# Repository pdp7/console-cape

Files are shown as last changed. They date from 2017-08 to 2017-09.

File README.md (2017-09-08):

# console-cape
"psuedo" cape for the BeagleBone to display the serial console from the FTDI header on a TFT LCD.  The purpose is to be able to view U-Boot bootloader messages from the BeagleBone without having to have a laptop and USB-to-serial cable.

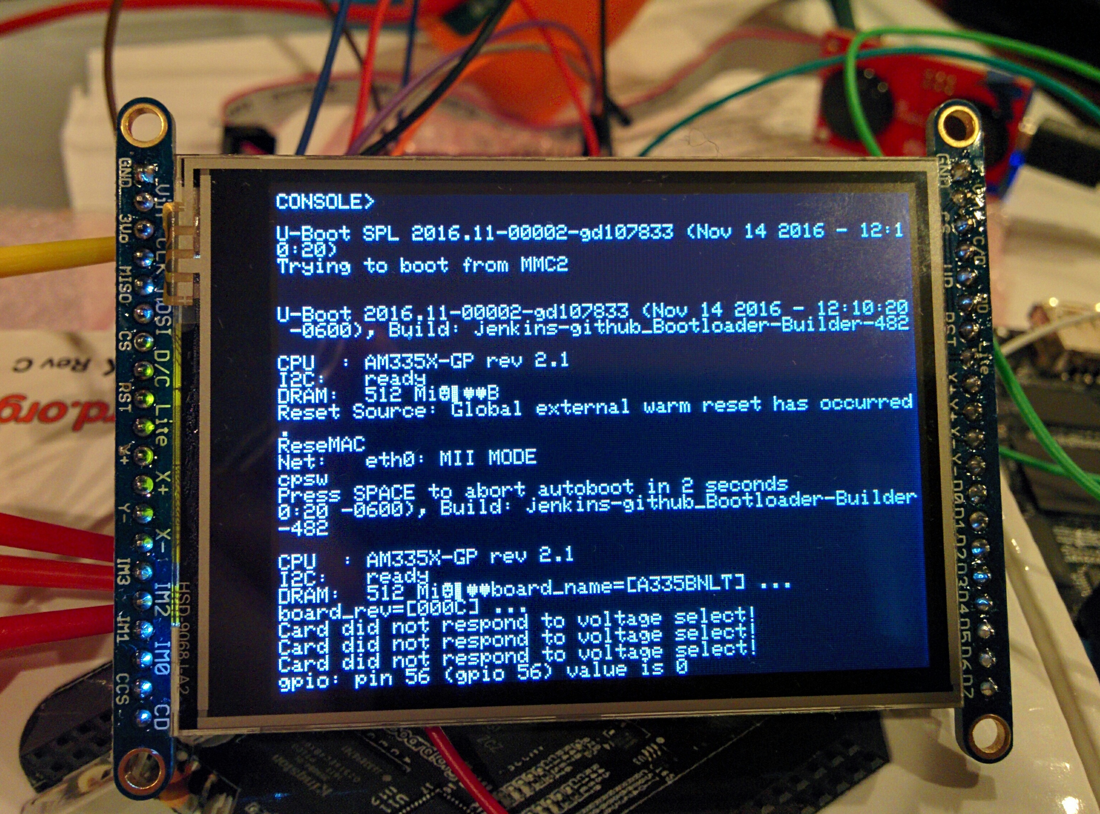
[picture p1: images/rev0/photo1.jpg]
Photo of rev 0 prototype (https://oshpark.com/projects/eaos4FIc)


### Revision 1
* added header for [Adafruit 2.8" TFT LCD ILI9341 [PID 1770]](https://www.adafruit.com/product/1770)
* Commit: [c39be8a](https://github.com/pdp7/console-cape/commit/c39be8ada9da4000ea4db9afabc903f09d86c110)
* OSH Park shared project: [eaos4FIc](https://oshpark.com/projects/eaos4FIc)
* Date: 2017-08-25
* Bill of Materials
  * [Digi-key cart](http://www.digikey.com/short/31dhr0)
  * [Digi-key CSV files](https://raw.githubusercontent.com/pdp7/console-cape/master/bom/rev1/rev1-digikey-bom.csv)
  * note: more parts are in cart than are needed to build 1 board
* md5sum: d4032f9a1d718b31ddc5a06508fa7b02
* order: HVzmEK87

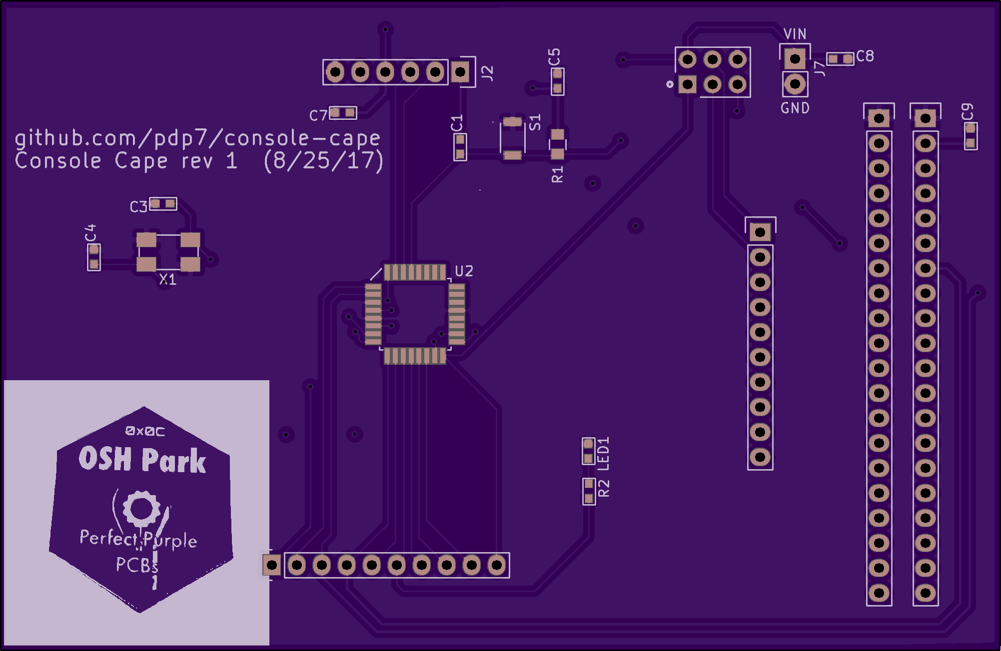
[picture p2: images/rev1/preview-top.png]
rev1 top preview (https://oshpark.com/projects/eaos4FIc)


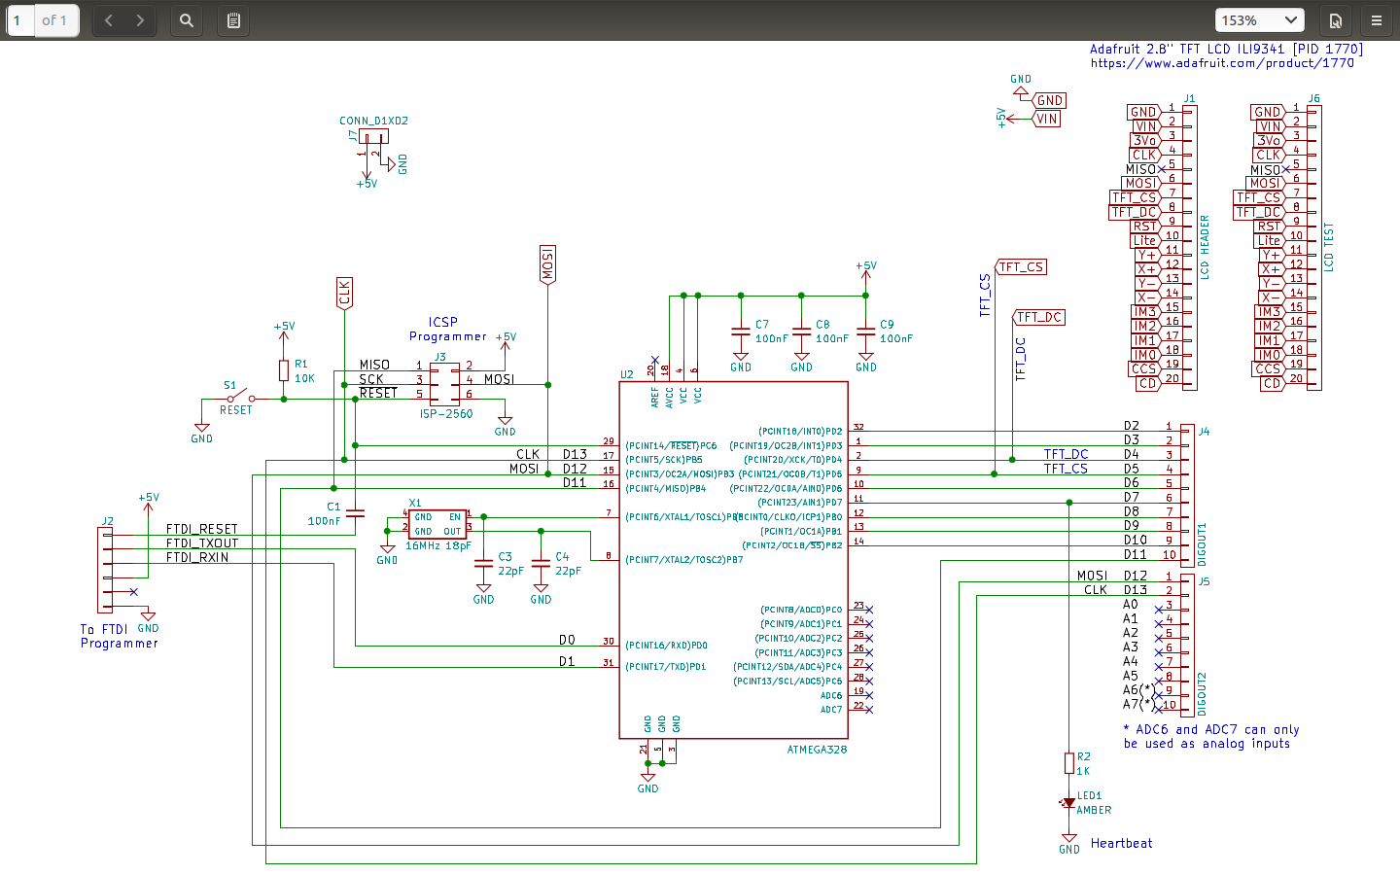
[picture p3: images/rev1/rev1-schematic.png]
rev1 schematic


### Revision 0
* rough alpha prototype that is essentially just WickerLib ATMega328 breakout board with 16MHz crystal
* [Photos of prototype on Google+](https://plus.google.com/+DrewFustini/posts/R8djs28UbCG)
* Commit: [9690673](https://github.com/pdp7/wickerlib/commit/96906732c141e468960d03e7d56b61da5f02cf5b)
* OSH Park shared project: [CjWyM5EL](https://oshpark.com/shared_projects/CjWyM5EL)

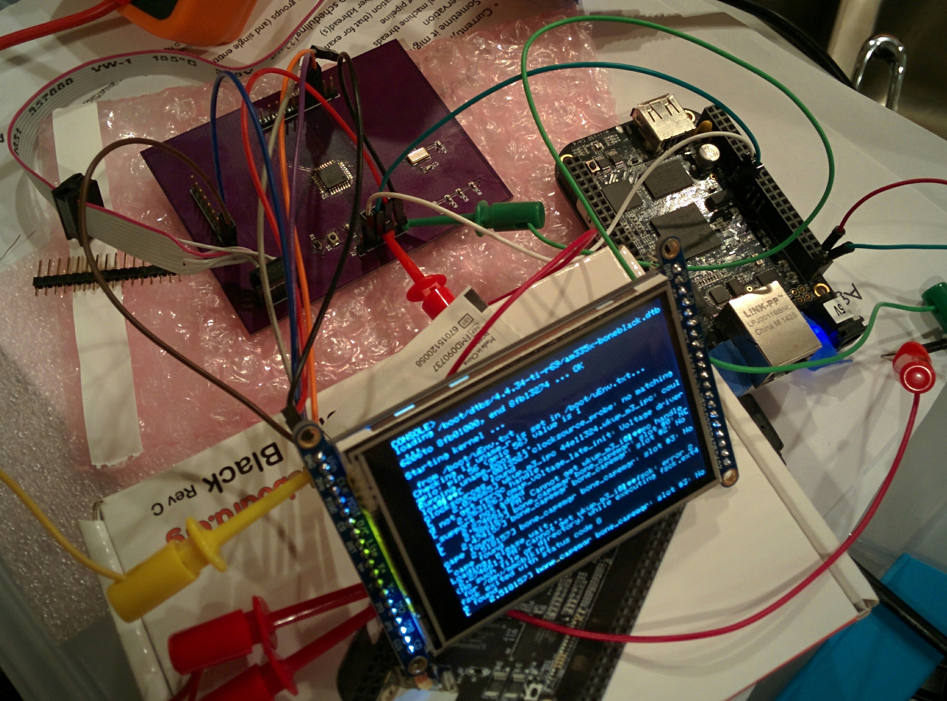
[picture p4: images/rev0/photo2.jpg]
Photo of rev 0 prototype


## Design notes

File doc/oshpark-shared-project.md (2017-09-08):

# UNTESTED!
# [Console Cape rev 1](https://github.com/pdp7/console-cape)
"psuedo" cape for the BeagleBone to display the serial console from the FTDI header on a TFT LCD.  The purpose is to be able to view U-Boot bootloader messages from the BeagleBone without having to have a laptop and USB-to-serial cable.

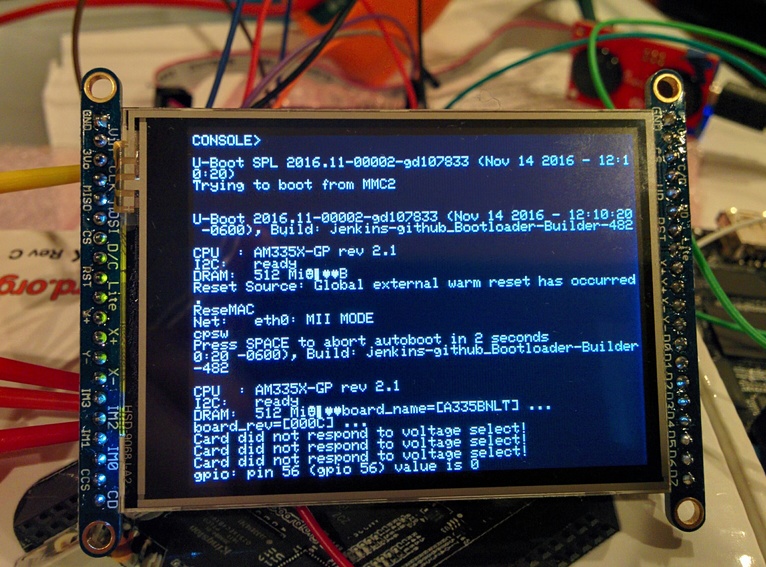
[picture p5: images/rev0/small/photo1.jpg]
Photo of rev 0 prototype


## Revision 1
* **UNTESTED**
* added header for [Adafruit 2.8" TFT LCD ILI9341 [PID 1770]](https://www.adafruit.com/product/1770)
* Commit: [c39be8a](https://github.com/pdp7/console-cape/commit/c39be8ada9da4000ea4db9afabc903f09d86c110)
* OSH Park shared project: [eaos4FIc](https://oshpark.com/projects/eaos4FIc)
* Date: 2017-08-25
* Bill of Materials
  * [Digi-key cart](http://www.digikey.com/short/31dhr0)
  * [Digi-key CSV files](https://raw.githubusercontent.com/pdp7/console-cape/master/bom/rev1/rev1-digikey-bom.csv)
  * note: more parts are in cart than are needed to build 1 board
* md5sum: d4032f9a1d718b31ddc5a06508fa7b02
* order: HVzmEK87

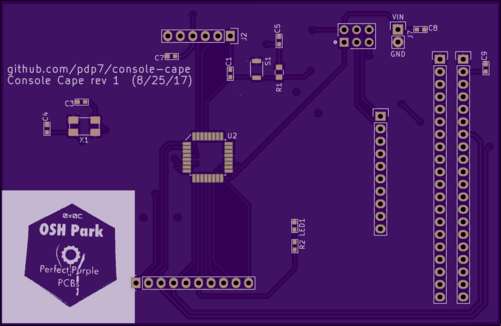
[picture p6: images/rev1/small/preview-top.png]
rev1 top preview


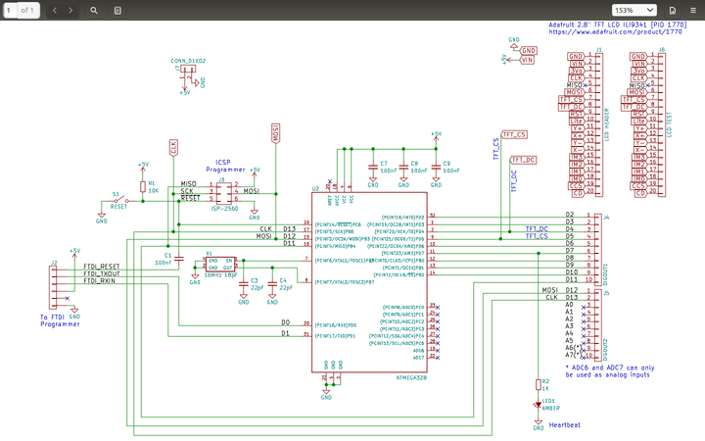
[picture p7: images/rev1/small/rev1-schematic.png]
rev1 schematic


## Revision 0
* rough alpha prototype that is essentially just WickerLib ATMega328 breakout board with 16MHz crystal
* [Photos of prototype on Google+](https://plus.google.com/+DrewFustini/posts/R8djs28UbCG)
* Commit: [9690673](https://github.com/pdp7/wickerlib/commit/96906732c141e468960d03e7d56b61da5f02cf5b)
* OSH Park shared project: [CjWyM5EL](https://oshpark.com/shared_projects/CjWyM5EL)

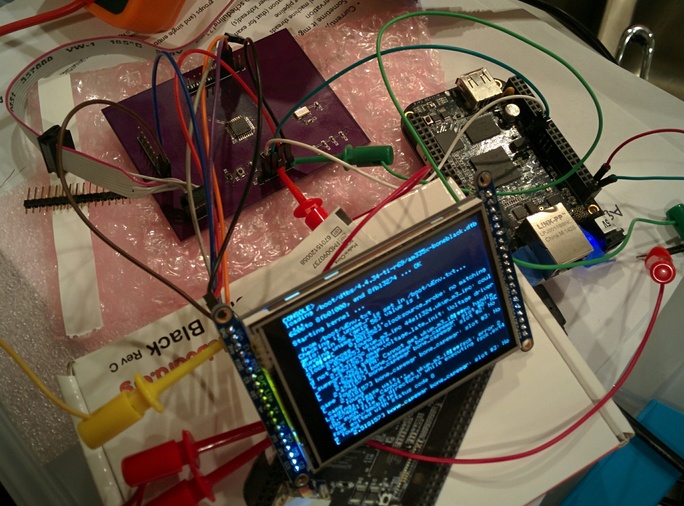
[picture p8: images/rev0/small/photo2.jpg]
Photo of rev 0 prototype


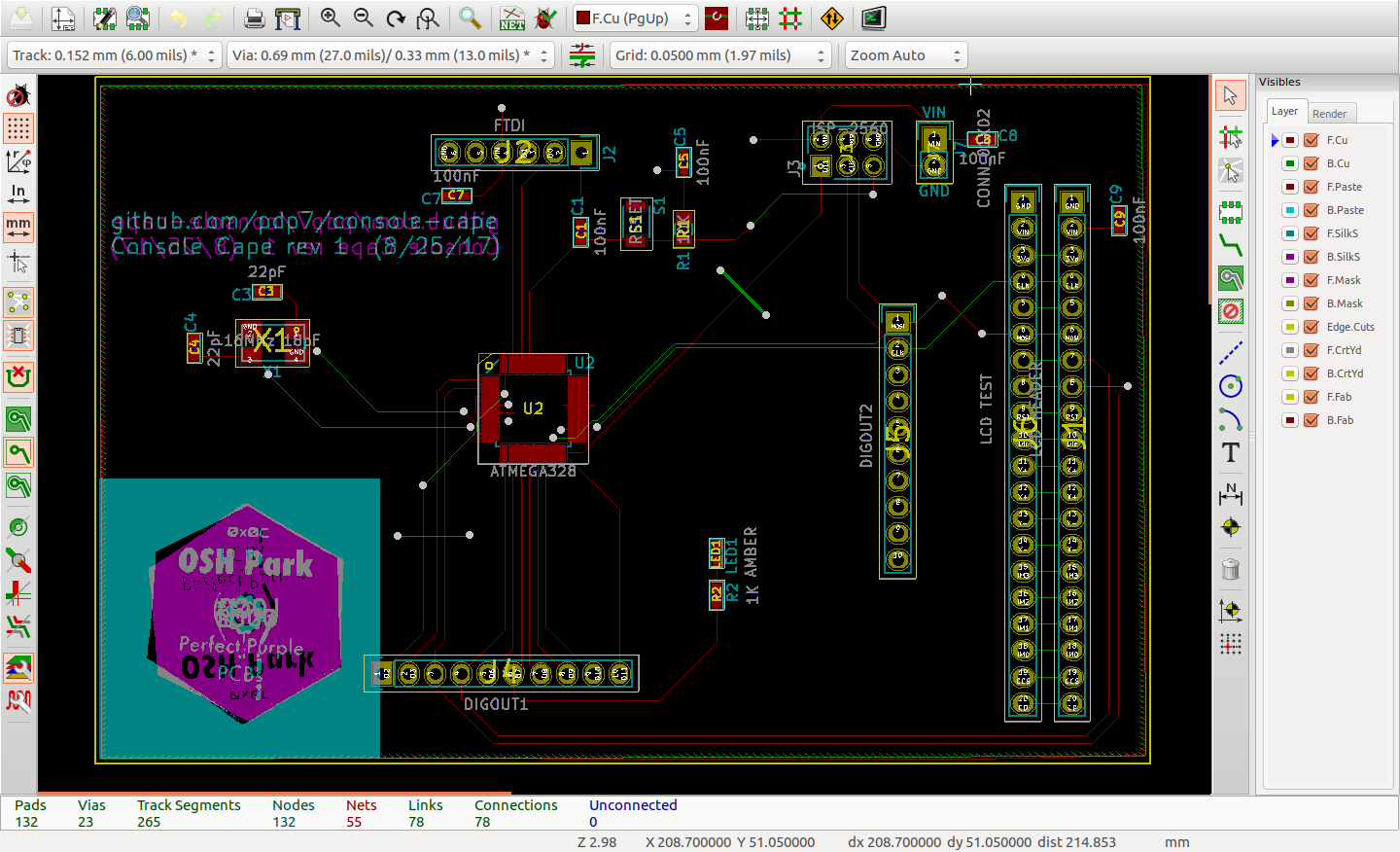
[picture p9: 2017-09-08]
images/rev1/rev1-layout.png

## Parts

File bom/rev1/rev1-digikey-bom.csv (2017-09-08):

Index | Quantity | Part Number | Description | Customer Reference | Available Quantity | Backorder Quantity | Unit Price USD | Extended Price USD
1 | 1 | 952-1985-ND | 6POS SIL VERTICAL PIN HEADER | J2 (CONSOLE CAP REV1) | 1 | 0 | 0.28000 | 0.28
2 | 2 | S7008-ND | CONN HEADER FEMALE 10POS.1" TIN | J4 J5 (CONSOLE CAP REV1) | 2 | 0 | 0.81000 | 1.62
3 | 10 | 399-9030-1-ND | CAP CER 22PF 25V C0G/NP0 0603 | C3 C4 (CONSOLE CAP REV1) | 10 | 0 | 0.06300 | 0.63
4 | 1 | 952-1902-ND | 20POS SIL VERTICAL PIN HEADER | J2 (CONSOLE CAP REV1) | 1 | 0 | 0.63000 | 0.63
5 | 10 | 311-10KARCT-ND | RES SMD 10K OHM 5% 1/8W 0805 | R1 (CONSOLE CAP REV1) | 10 | 0 | 0.01900 | 0.19
6 | 1 | 952-1921-ND | 2X3POS DIL VERTICAL PIN HEADER | J3 (CONSOLE CAP REV1) | 1 | 0 | 0.33000 | 0.33
7 | 2 | SW1020CT-ND | SWITCH TACTILE SPST-NO 0.05A 12V | S1 (CONSOLE CAP REV1) | 2 | 0 | 1.00000 | 2.00
8 | 2 | 952-1843-ND | 10POS SIL VERTICAL PIN HEADER | J4 J5 (CONSOLE CAP REV1) | 2 | 0 | 0.37000 | 0.74
9 | 3 | ATMEGA328P-AURCT-ND | IC MCU 8BIT 32KB FLASH 32TQFP | U2 (CONSOLE CAP REV1) | 3 | 0 | 2.18000 | 6.54
10 | 3 | CTX1206CT-ND | CRYSTAL 16.0000MHZ 18PF SMD | X1 (CONSOLE CAP REV1) | 3 | 0 | 1.14000 | 3.42
11 | 10 | 490-3285-1-ND | CAP CER 0.1UF 100V X7R 0603 | C1 C5 C7 C8 C9 (CONSOLE CAP REV1) | 10 | 0 | 0.15600 | 1.56
12 | 1 | 1276-3484-1-ND | RES SMD 1K OHM 1% 1/10W 0603 | R2 (CONSOLE CAP REV1) | 1 | 0 | 0.10000 | 0.10
13 | 2 | S7018-ND | CONN HEADER FEMALE 20POS.1" TIN | LCD (CONSOLE CAP REV1) | 2 | 0 | 1.53000 | 3.06
14 | 1 | S7000-ND | CONN HEADER FEMALE 2POS .1" TIN | J7 (CONSOLE CAP REV1) | 1 | 0 | 0.49000 | 0.49
15 | 1 | 929974E-01-06-ND | CONN RECEPT .100 SNGL STR 6POS | J2 (CONSOLE CAP REV1) | 1 | 0 | 0.90000 | 0.90
16 | 1 | S7004-ND | CONN HEADER FEMALE 6POS .1" TIN | J2 (CONSOLE CAP REV1) | 1 | 0 | 0.68000 | 0.68
17 | 10 | 311-1.00KHRCT-ND | RES SMD 1K OHM 1% 1/10W 0603 | R2 (CONSOLE CAP REV1) | 10 | 0 | 0.01500 | 0.15
18 | 1 | 475-2512-1-ND | LED RED DIFFUSED 0603 SMD | LED1 (CONSOLE CAP REV1) | 1 | 0 | 0.26000 | 0.26
19 | 1 | 511-1578-1-ND | LED GREEN DIFFUSED 0603 SMD | LED1 (CONSOLE CAP REV1) | 1 | 0 | 0.34000 | 0.34
20 | 1 | 67-1550-1-ND | LED YELLOW DIFFUSED 0603 SMD | LED1 (CONSOLE CAP REV1) | 1 | 0 | 0.39000 | 0.39
21 | 1 | 67-1551-1-ND | LED RED DIFFUSED 0603 SMD | LED1 (CONSOLE CAP REV1) | 1 | 0 | 0.44000 | 0.44
22 | 1 | 67-1549-1-ND | LED GREEN DIFFUSED 0603 SMD | LED1 (CONSOLE CAP REV1) | 1 | 0 | 0.39000 | 0.39

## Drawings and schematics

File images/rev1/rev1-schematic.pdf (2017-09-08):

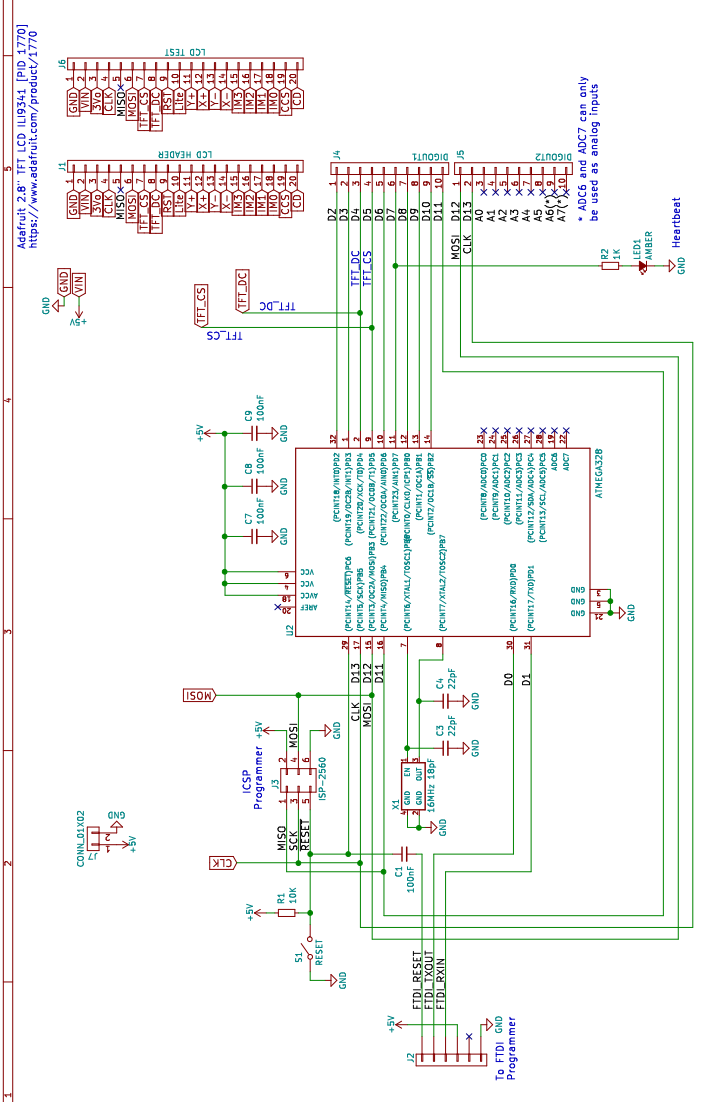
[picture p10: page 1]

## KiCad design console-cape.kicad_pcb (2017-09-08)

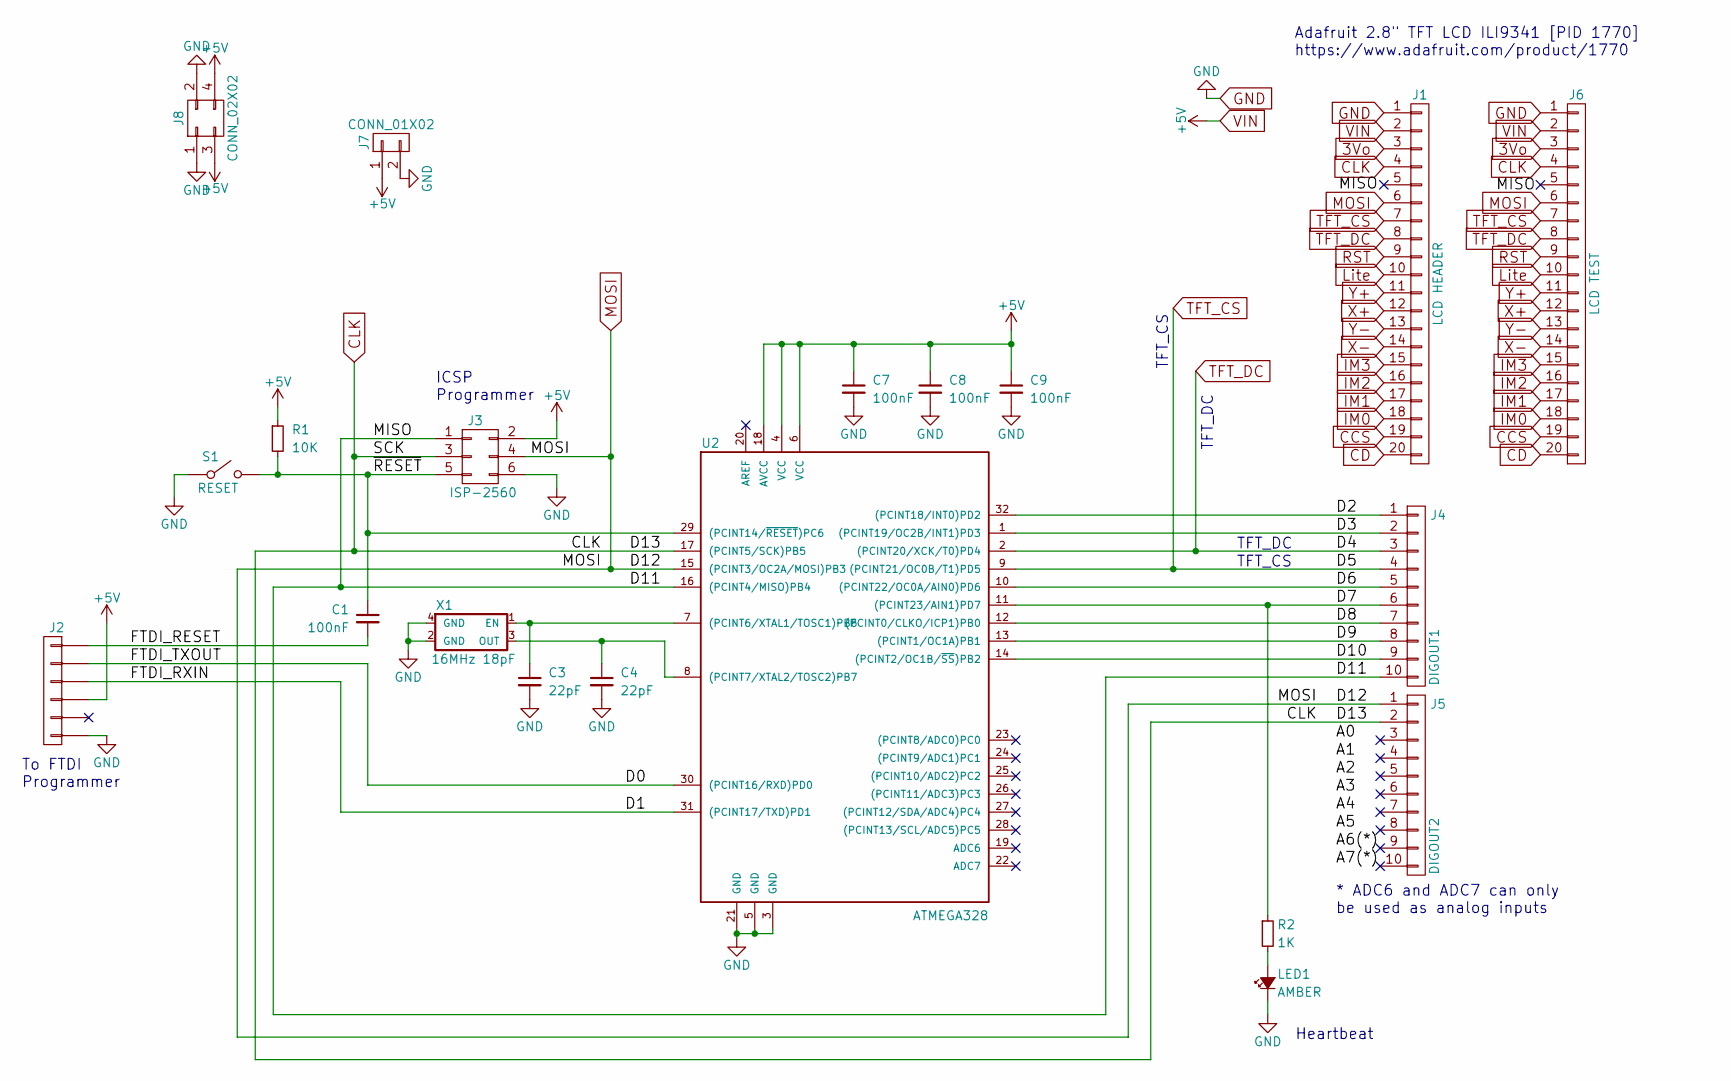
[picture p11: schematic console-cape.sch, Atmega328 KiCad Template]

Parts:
C1, C7, C8, C9: 100nF; RLC-0603-SMD
C3, C4: 22pF; RLC-0603-SMD
J1: LCD HEADER; CONN-HEADER-STRAIGHT-P2.54MM-1x20
J2: FTDI; CONN-HEADER-STRAIGHT-P2.54MM-1x06
J3: ISP-2560; CONN-HEADER-STRAIGHT-P2.54MM-2x03
J4: DIGOUT1; CONN-HEADER-STRAIGHT-P2.54MM-1x10
J5: DIGOUT2; CONN-HEADER-STRAIGHT-P2.54MM-1x10
J6: LCD TEST; CONN-HEADER-STRAIGHT-P2.54MM-1x20
J7: CONN_01X02; CONN-HEADER-STRAIGHT-P2.54MM-1x02
J8: CONN_02X02; CONN-HEADER-STRAIGHT-P2.54MM-2x02
LED1: AMBER; RLC-0603-SMD
R1: 10K; RLC-0805-SMD
R2: 1K; RLC-0603-SMD
S1: RESET; SWITCH-OMRON-MOMENTARY-SMD-B3U-1000P
U2: ATMEGA328; TQFP-32-7x7MM-P0.8MM
X1: 16MHz 18pF; CRYSTAL-CTS-4SMD

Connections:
3Vo: J1.3, J6.3
/D0: J2.2, U2.30 ((PCINT16/RXD)PD0)
/D1: J2.3, U2.31 ((PCINT17/TXD)PD1)
/D2: J4.1, U2.32 ((PCINT18/INT0)PD2)
/D3: J4.2, U2.1 ((PCINT19/OC2B/INT1)PD3)
/D6: J4.5, U2.10 ((PCINT22/OC0A/AIN0)PD6)
/D7: J4.6, R2.1, U2.11 ((PCINT23/AIN1)PD7)
/D8: J4.7, U2.12 ((PCINT0/CLKO/ICP1)PB0)
/D9: J4.8, U2.13 ((PCINT1/OC1A)PB1)
/D10: J4.9, U2.14 ((PCINT2/OC1B/~SS~)PB2)
/D11: J3.1, J4.10, U2.16 ((PCINT4/MISO)PB4)
/FTDI_RESET: C1.2, J2.1
/~RESET: C1.1, J3.5, R1.2, S1.2, U2.29 ((PCINT14/~RESET~)PC6)
CCS: J1.19, J6.19
CD: J1.20, J6.20
CLK: J1.4, J3.3, J5.2, J6.4, U2.17 ((PCINT5/SCK)PB5)
GND: C3.2, C4.2, C7.2, C8.2, C9.2, J1.1, J2.6, J3.6, J6.1, J7.2, J8.1, J8.2, LED1.1 (K), S1.1, U2.3 (GND), U2.5 (GND), U2.21 (GND), X1.2 (GND), X1.4 (GND); also elsewhere on the board
IM0: J1.18, J6.18
IM1: J1.17, J6.17
IM2: J1.16, J6.16
IM3: J1.15, J6.15
Lite: J1.10, J6.10
MOSI: J1.6, J3.4, J5.1, J6.6, U2.15 ((PCINT3/OC2A/MOSI)PB3)
unnamed: C3.1, U2.7 ((PCINT6/XTAL1/TOSC1)PB6), X1.1 (EN)
unnamed: C4.1, U2.8 ((PCINT7/XTAL2/TOSC2)PB7), X1.3 (OUT)
unnamed: LED1.2 (A), R2.2
RST: J1.9, J6.9
TFT_CS: J1.7, J4.4, J6.7, U2.9 ((PCINT21/OC0B/T1)PD5)
TFT_DC: J1.8, J4.3, J6.8, U2.2 ((PCINT20/XCK/T0)PD4)
VIN: C7.1, C8.1, C9.1, J1.2, J2.4, J3.2, J6.2, J7.1, J8.3, J8.4, R1.1, U2.4 (VCC), U2.6 (VCC), U2.18 (AVCC); also elsewhere on the board
X+: J1.12, J6.12
X-: J1.14, J6.14
Y+: J1.11, J6.11
Y-: J1.13, J6.13

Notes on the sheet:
To FTDI Programmer
ICSP Programmer
* ADC6 and ADC7 can only be used as analog inputs
Heartbeat
TFT_DC
TFT_CS
Adafruit 2.8" TFT LCD ILI9341 [PID 1770] https://www.adafruit.com/product/1770

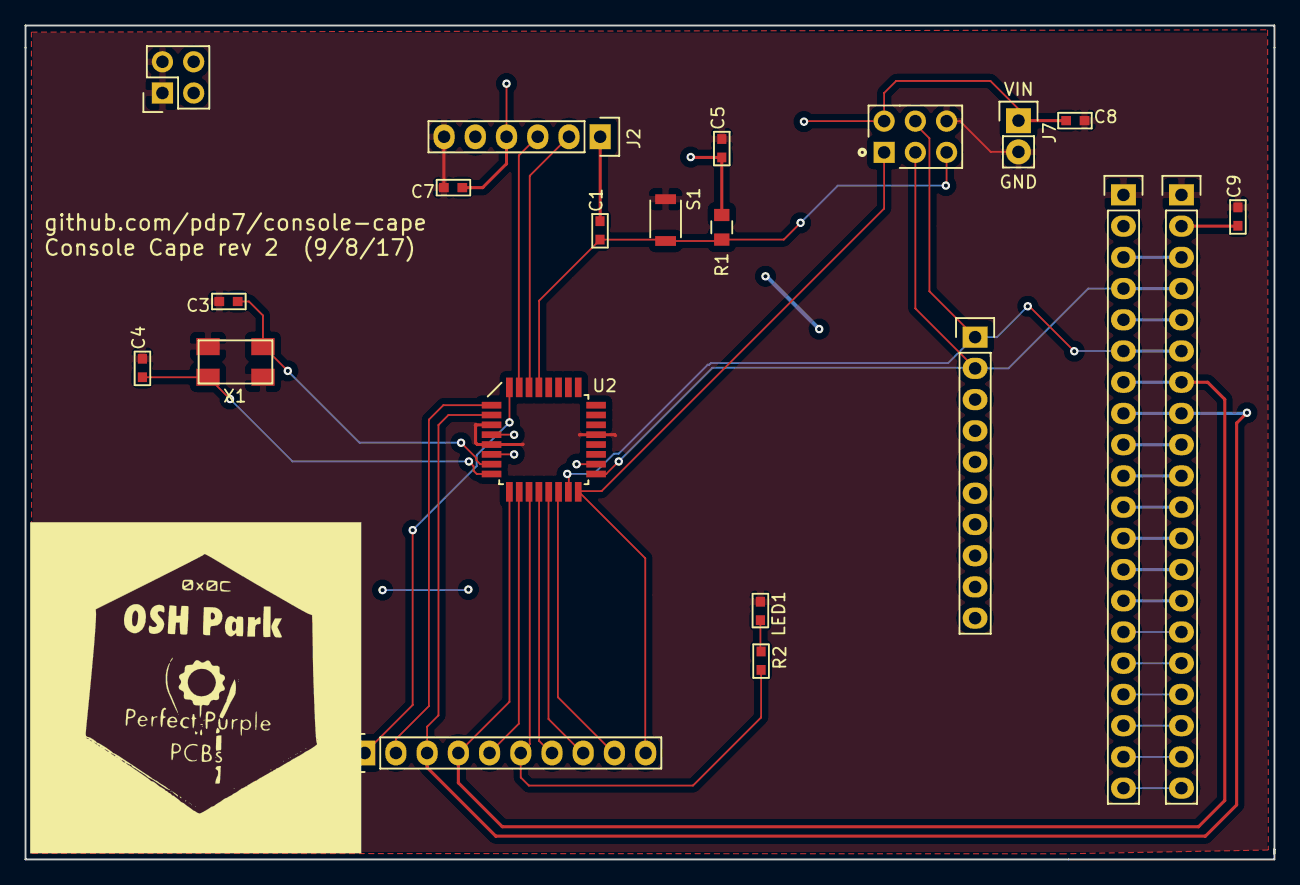
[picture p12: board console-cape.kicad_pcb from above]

Board: 2 copper layers, 101.6 x 67.8 mm, 21 parts (0 on the bottom side), 34 nets.

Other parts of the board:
C5: 100nF; RLC-0603-SMD

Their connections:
GND: C5.2; also elsewhere on the board
VIN: C5.1; also elsewhere on the board

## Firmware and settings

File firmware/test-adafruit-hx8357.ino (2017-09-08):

/***************************************************
  This is an example sketch for the Adafruit 2.2" SPI display.
  This library works with the Adafruit 2.2" TFT Breakout w/SD card
  ----> http://www.adafruit.com/products/1480

  Check out the links above for our tutorials and wiring diagrams
  These displays use SPI to communicate, 4 or 5 pins are required to
  interface (RST is optional)
  Adafruit invests time and resources providing this open source code,
  please support Adafruit and open-source hardware by purchasing
  products from Adafruit!

  Written by Limor Fried/Ladyada for Adafruit Industries.
  MIT license, all text above must be included in any redistribution
 ****************************************************/

#include "SPI.h"
#include "Adafruit_GFX.h"
//#include "Adafruit_ILI9340.h"
//#include "Adafruit_ILI9341.h"
#include "Adafruit_HX8357.h"

#if defined(__SAM3X8E__)
#undef __FlashStringHelper::F(string_literal)
#define F(string_literal) string_literal
#endif

// These are the pins used for the UNO
// for Due/Mega/Leonardo use the hardware SPI pins (which are different)
#define _sclk 2 // uno hw spi: 13, icsp: 3
#define _mosi 3 // uno hw spi: 12, icsp: 4
#define _dc 4
#define _cs 5
#define _rst 6
#define _miso 8
// Using software SPI is really not suggested, its incredibly slow
//Adafruit_ILI9340 tft = Adafruit_ILI9340(_cs, _dc, _mosi, _sclk, _rst, _miso);
// Use hardware SPI
//Adafruit_ILI9340 tft = Adafruit_ILI9340(_cs, _dc, _rst);
// For the Adafruit shield, these are the default.
#define TFT_DC 4
#define TFT_CS 5
//Adafruit_ILI9341 tft = Adafruit_ILI9341(TFT_CS, TFT_DC);
Adafruit_HX8357 tft = Adafruit_HX8357(TFT_CS, TFT_DC);
#define LED_PIN 7

void setup() {
  pinMode(LED_PIN, OUTPUT);
  digitalWrite(LED_PIN, HIGH);
  Serial.begin(115200);
  while (!Serial);
  //tft.begin();
  tft.begin(HX8357D);
  tft.setRotation(3);
  //tft.fillScreen(ILI9341_BLACK);
  tft.fillScreen(HX8357_BLACK);
  tft.setCursor(0, 0);
  //tft.setTextColor(ILI9341_WHITE);
  tft.setTextColor(HX8357_WHITE);
  tft.setTextSize(1);
  tft.setTextWrap(true);
  tft.println("CONSOLE>");
  digitalWrite(LED_PIN, LOW);
}

void loop(void) {
  /*tft.println("[1020358.156608] mwifiex_pcie 0000:01:00.0: PREP_CMD: FW in reset state");
    tft.println("[1020358.156612] mwifiex_pcie 0000:01:00.0: scan failed: -1");
    tft.println("[1020358.156608] mwifiex_pcie 0000:01:00.0: PREP_CMD: FW in reset state");
    tft.println("[1020358.156612] mwifiex_pcie 0000:01:00.0: scan failed: -1");
    tft.println("[1020358.156608] mwifiex_pcie 0000:01:00.0: PREP_CMD: FW in reset state");
    tft.println("[1020358.156612] mwifiex_pcie 0000:01:00.0: scan failed: -1");
    tft.println("[1020358.156608] mwifiex_pcie 0000:01:00.0: PREP_CMD: FW in reset state");
    tft.println("[1020358.156612] mwifiex_pcie 0000:01:00.0: scan failed: -1");
    tft.println("[1020358.156608] mwifiex_pcie 0000:01:00.0: PREP_CMD: FW in reset state");
    tft.println("[1020358.156612] mwifiex_pcie 0000:01:00.0: scan failed: -1");
    tft.println("[1020358.156608] mwifiex_pcie 0000:01:00.0: PREP_CMD: FW in reset state");
    tft.println("[1020358.156612] mwifiex_pcie 0000:01:00.0: scan failed: -1");
    delay(500);*/
  //char incomingByte = 0;   // for incoming serial data
  char serbuf[255];
  if (Serial.available() > 0) {
    digitalWrite(LED_PIN, HIGH);
    // read the incoming byte:
    //incomingByte = Serial.read();
    Serial.readBytes(serbuf, 255);
    // say what you got:
    //Serial.print(incomingByte);
    tft.print(serbuf);
    delay(10);
    digitalWrite(LED_PIN, LOW);
  }
}

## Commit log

2017-08-26 add initial files
    [atmega328.kicad_pcb, atmega328.sch, console-cape.kicad_pcb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]
2017-08-26 clean up traces on top and bottom copper
    [console-cape.kicad_pcb]
2017-08-26 add gerbers to order stencil
    [console-cape-B.Cu.gbl, console-cape-B.Fab.gbr, console-cape-B.Mask.gbs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]
2017-08-26 add project images for rev0 and rev1
    [console-cape-B.Cu.gbl, console-cape-B.Fab.gbr, console-cape-B.Mask.gbs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]
2017-08-26 add rev1 digi-key bom
    [rev1-digikey-bom.csv]
2017-08-26 add shared project documentation and resize schematic
2017-08-27 add Arduino test for Adafruit 3.5" LCD with HX8357
2017-09-08 added header to get GND and 3V3 from BBB P9
    [console-cape.kicad_pcb, console-cape.sch]

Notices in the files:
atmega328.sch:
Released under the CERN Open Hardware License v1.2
